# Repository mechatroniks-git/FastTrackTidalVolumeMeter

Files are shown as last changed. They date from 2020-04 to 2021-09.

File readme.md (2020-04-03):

# Fast Track Tidal Volume Meter

Open Source device to measure tidal volume

## Background

Standalone tidal flow meters do not exist. The goal of this device is to allow anyone to have independent monitoring of tidal volume. 

### Making Device

Currently the device is made using the following

* Olimex ESP32-POE-ISO
* SSD1306 .96" OLED
* Sensirion SFM3300 flow sensor
* PCBA (in development)

## Notes

FDA HAS NOT AUTHORIZED USE OF THIS DEVICE, DESIGNS, SOURCE CODE OR DESCRIPTIONS.

## Licence

CERN Open Hardware Licence Version 2 - Permissive See licence file for more info.

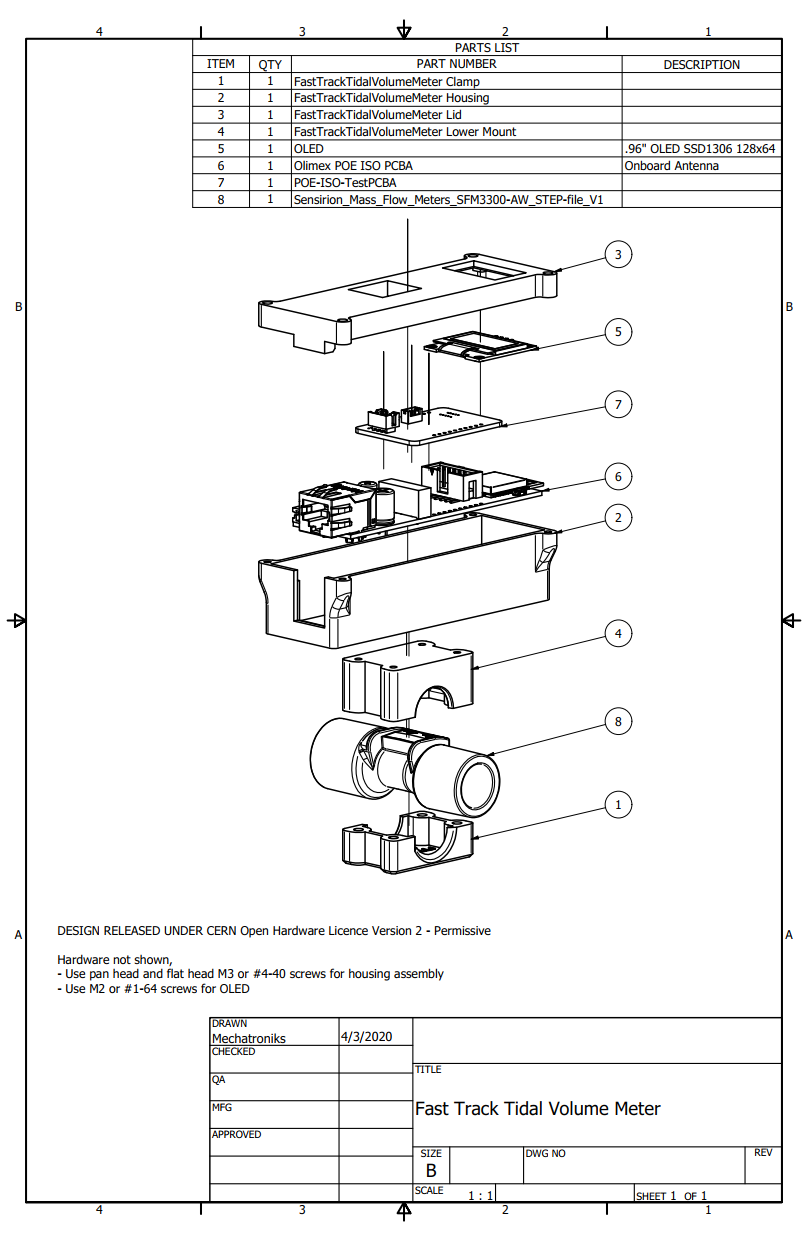
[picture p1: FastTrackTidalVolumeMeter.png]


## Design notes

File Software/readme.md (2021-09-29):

For Spirometer, use the code in this folder

For a simple flow meter useful for testing, use the code in /Flow Meter Build folder. Note, this code doesn't use wifi.

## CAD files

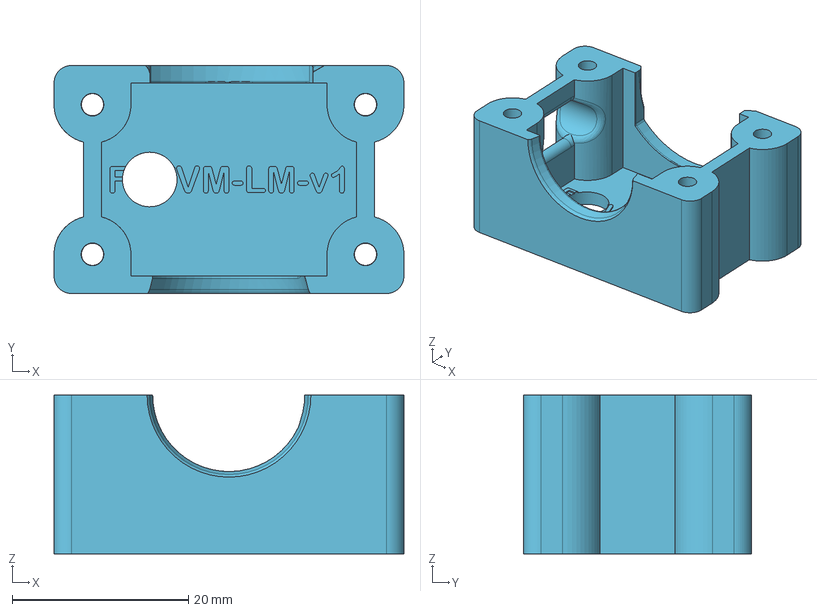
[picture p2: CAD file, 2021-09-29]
Mechanical/makeParts/FastTrackTidalVolumeMeter Lower Mount.stp
39.7 x 25.9 x 18.0 mm

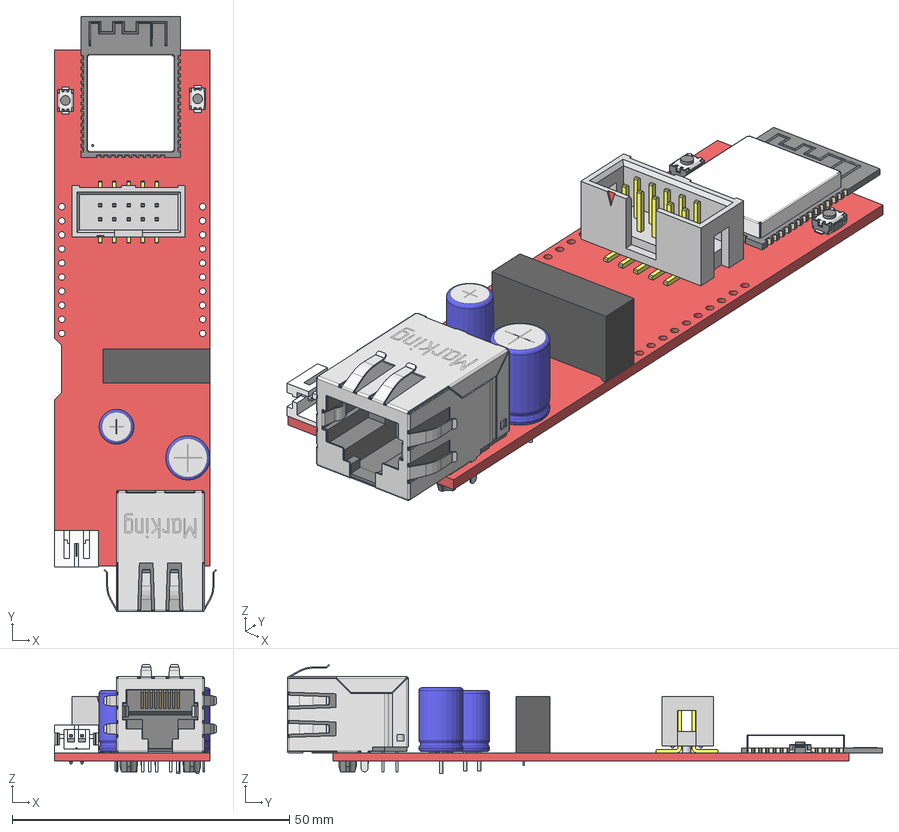
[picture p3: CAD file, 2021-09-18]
PCB/Olimex POE ISO PCBA.stp
29.2 x 107.4 x 19.7 mm
Olimex POE ISO PCB
Olimex POE ISO C29
Olimex POE ISO C27
insulator
shielding
ESP-WROOM-32D
Pushbutton IT1185AU2 x 2
Olimex POE ISO BAT1 JST PH 2 Pin DW02R
User Library-HTST-105-01-F-DV-A__HTST-105-01-DV-A_header
User Library-HTST-105-01-F-DV-A__HTST-First_Position_Indicator
User Library-HTST-105-01-F-DV-A__T-1S6-05-01-DV_
Olimex POE ISO DCDC1 Mornsun F0505S-2WR2

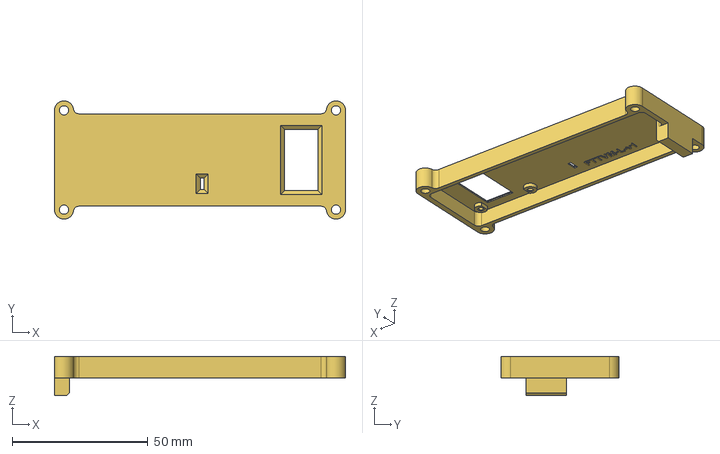
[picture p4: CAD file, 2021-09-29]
Mechanical/makeParts/FastTrackTidalVolumeMeter Lid.stp
107.0 x 43.5 x 14.5 mm

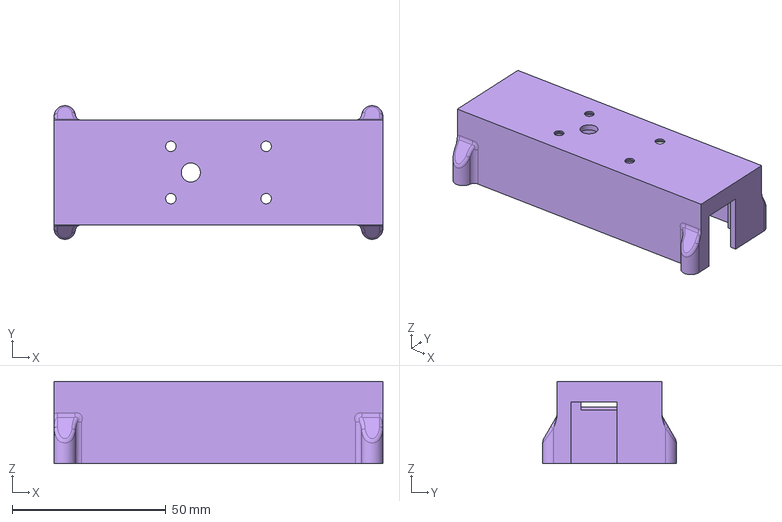
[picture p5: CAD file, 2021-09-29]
Mechanical/makeParts/FastTrackTidalVolumeMeter Housing.stp
107.0 x 43.5 x 26.8 mm

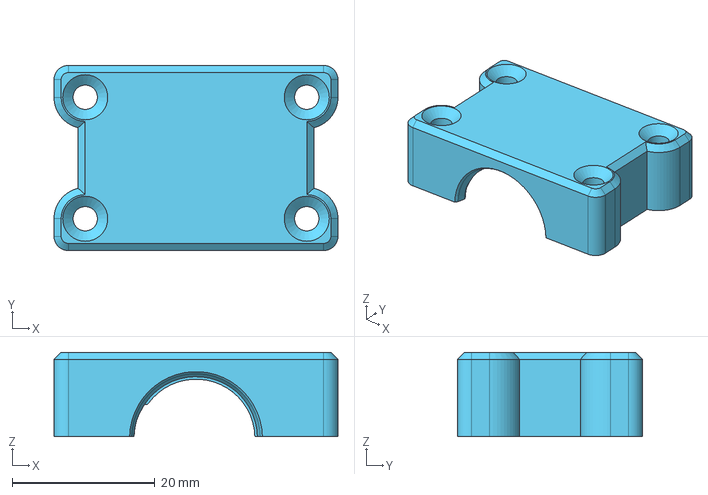
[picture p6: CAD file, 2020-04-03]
Mechanical/makeParts/FastTrackTidalVolumeMeter Clamp.stp
39.7 x 25.9 x 11.8 mm

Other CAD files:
Mechanical/makeParts/FastTrackTidalVolumeMeter Clamp.stl
Mechanical/makeParts/FastTrackTidalVolumeMeter Housing.stl
Mechanical/makeParts/FastTrackTidalVolumeMeter Lid.stl
Mechanical/makeParts/FastTrackTidalVolumeMeter Lower Mount.stl

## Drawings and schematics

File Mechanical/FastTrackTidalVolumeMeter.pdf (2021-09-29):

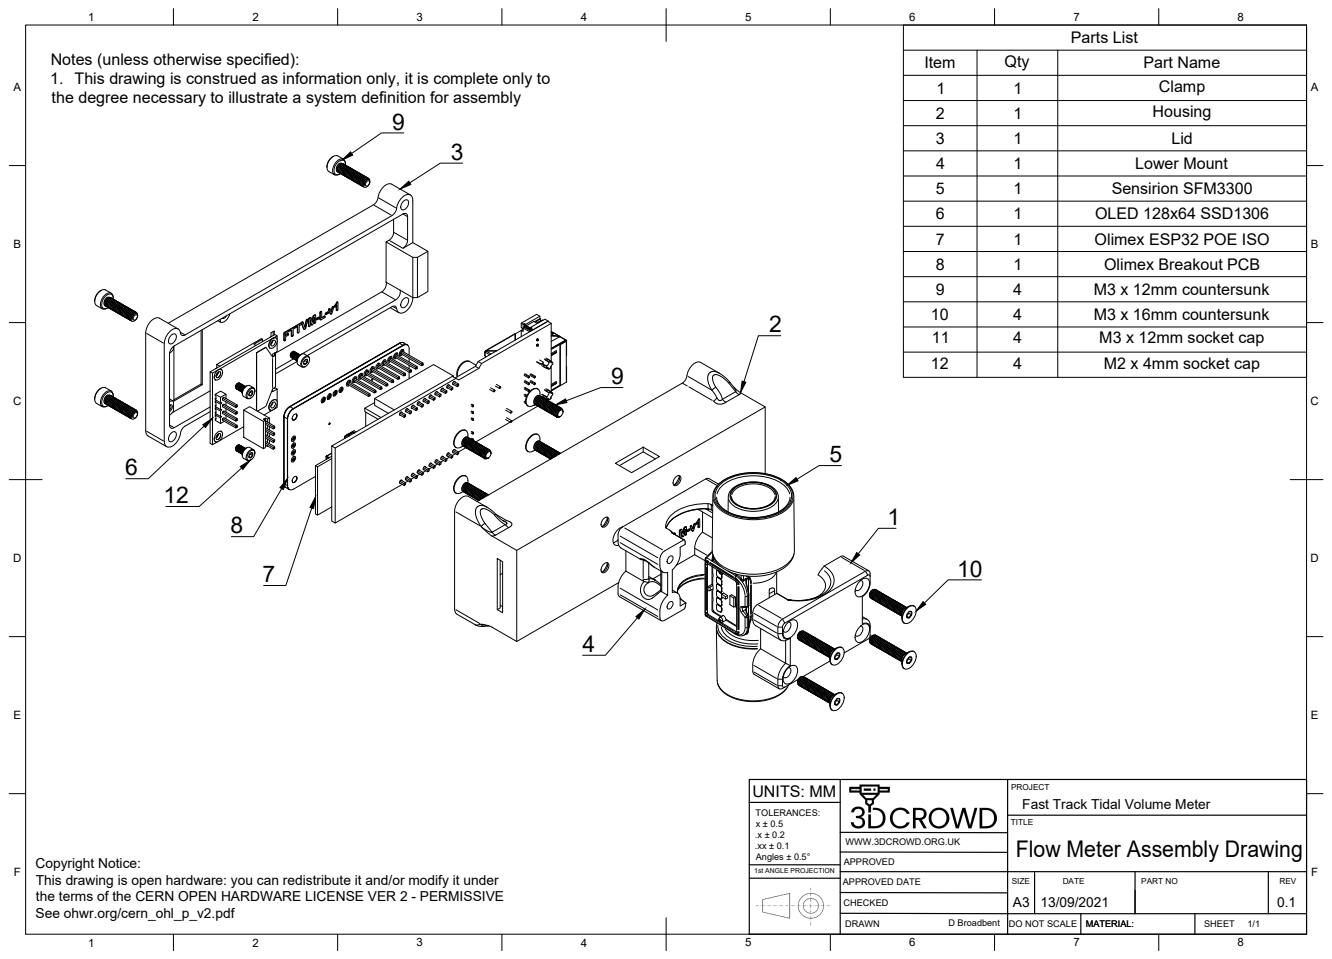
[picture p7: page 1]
UNITS: MM; Angles ± 0.5° 1st ANGLE PROJECTION; SIZE; DATE; PART NO; DO NOT SCALE; MATERIAL:; APPROVED DATE; D Broadbent; Parts List

Notes (unless otherwise specified):
1. This drawing is construed as information only, it is complete only to
the degree necessary to illustrate a system definition for assembly

Item | Qty | Part Name
1 | 1 | Clamp
2 | 1 | Housing
3 | 1 | Lid
4 | 1 | Lower Mount
5 | 1 | Sensirion SFM3300
6 | 1 | OLED 128x64 SSD1306
7 | 1 | Olimex ESP32 POE ISO
8 | 1 | Olimex Breakout PCB
9 | 4 | M3 x 12mm countersunk
10 | 4 | M3 x 16mm countersunk
11 | 4 | M3 x 12mm socket cap
12 | 4 | M2 x 4mm socket cap

PROJECT
Fast Track Tidal Volume Meter

TITLE
Flow Meter Assembly Drawing

WWW.3DCROWD.ORG.UK

Copyright Notice:
This drawing is open hardware: you can redistribute it and/or modify it under
the terms of the CERN OPEN HARDWARE LICENSE VER 2 - PERMISSIVE
See ohwr.org/cern_ohl_p_v2.pdf

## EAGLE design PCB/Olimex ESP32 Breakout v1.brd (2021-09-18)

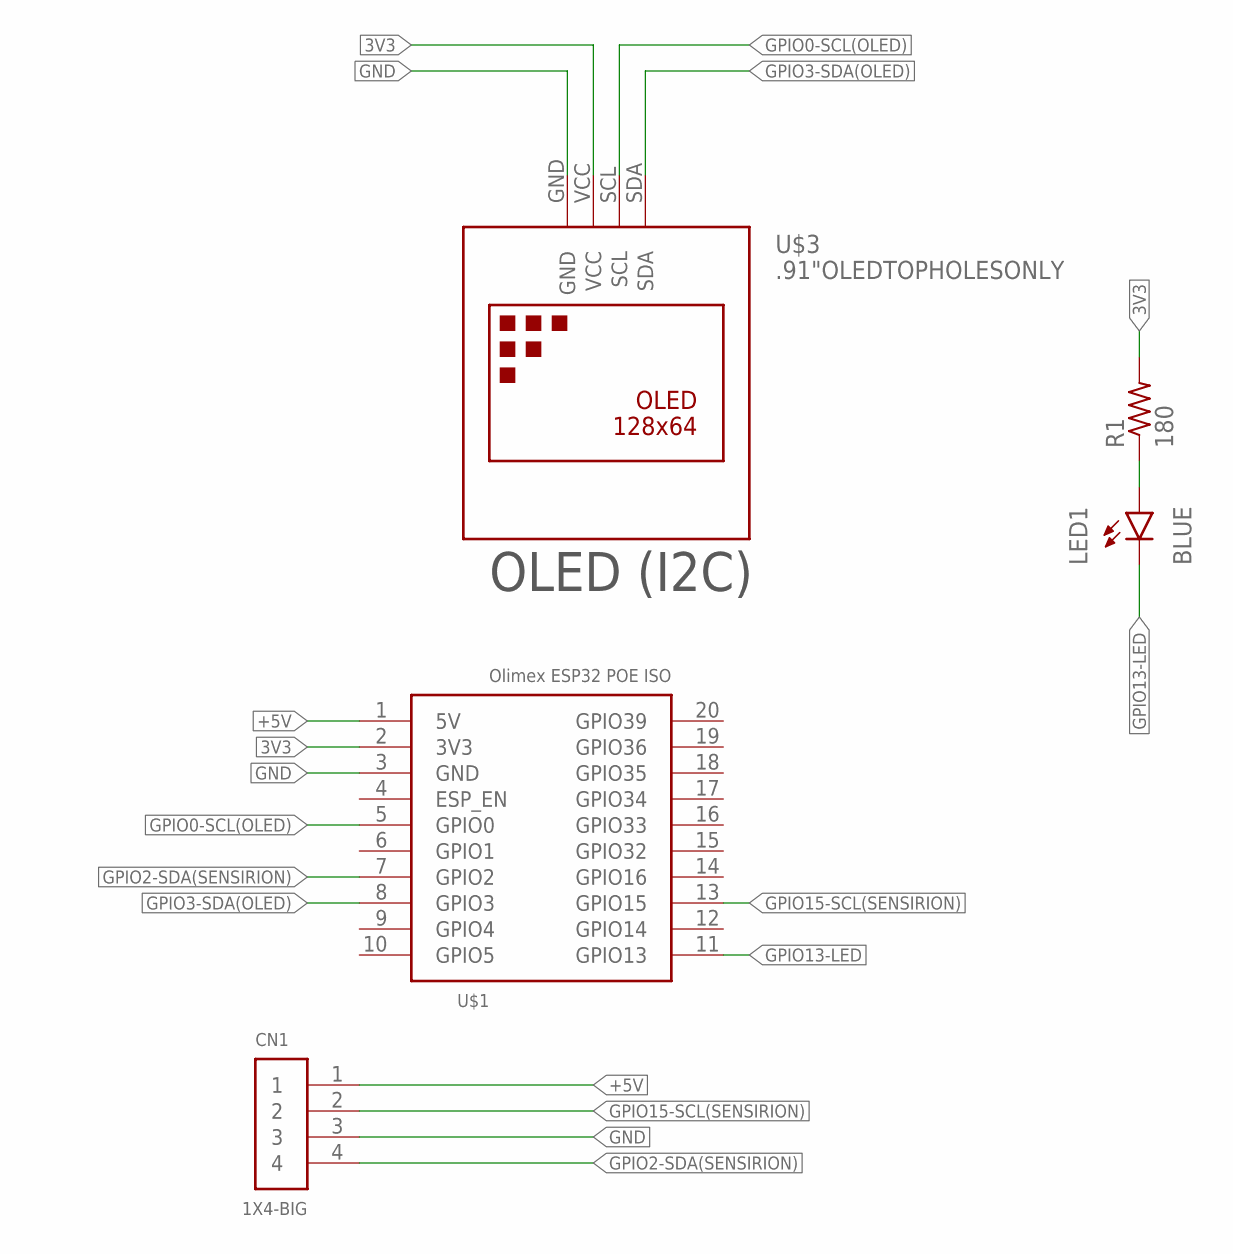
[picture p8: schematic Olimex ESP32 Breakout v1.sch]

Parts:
CN1: 1X4-BIG; 1X04-BIG
LED1: BLUE; LED-1206
R1: 180; R0805
U$1: OLIMEX_POE_ISOPOEISO; OLIMEX_POE_ISO
U$3: .91"OLEDTOPHOLESONLY; .96"OLED-TOPHOLESONLY

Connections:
3V3: R1.2, U$1.2 (3V3), U$3.VCC
+5V: CN1.1, U$1.1 (5V)
BLUEX: LED1.A, R1.1
GND: CN1.3, U$1.3 (GND), U$3.GND
GPIO0-SCL(OLED): U$1.5 (GPIO0), U$3.SCL
GPIO2-SDA(SENSIRION): CN1.4, U$1.7 (GPIO2)
GPIO3-SDA(OLED): U$1.8 (GPIO3), U$3.SDA
GPIO13-LED: LED1.C, U$1.11 (GPIO13)
GPIO15-SCL(SENSIRION): CN1.2, U$1.13 (GPIO15)

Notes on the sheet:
OLED (I2C)

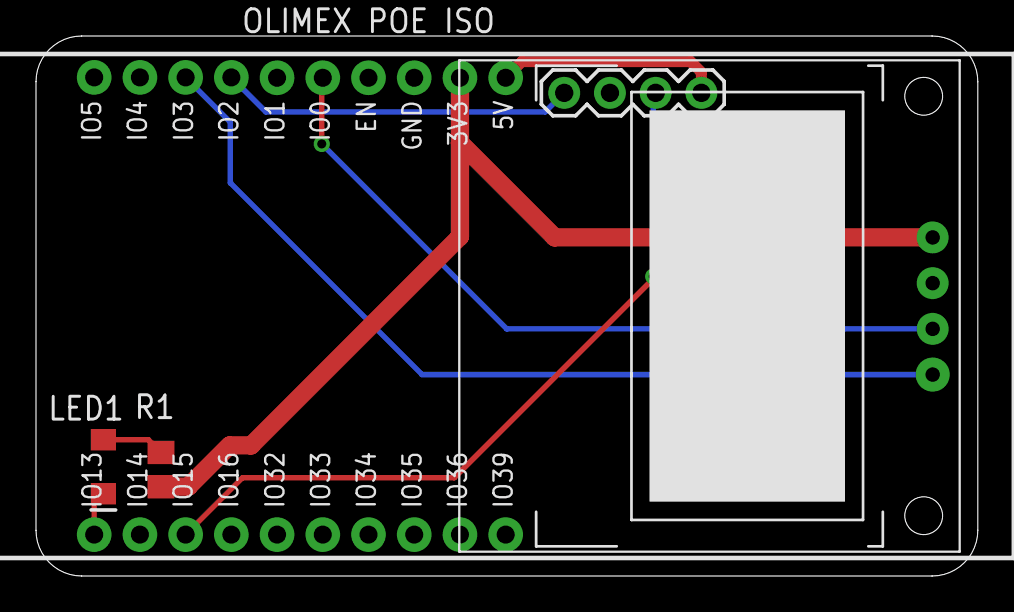
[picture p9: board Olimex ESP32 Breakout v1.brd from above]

Board: 2 copper layers, 52.3 x 30.0 mm, 5 parts (0 on the bottom side), 9 nets.

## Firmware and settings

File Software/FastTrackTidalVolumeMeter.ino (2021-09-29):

/*
Copyright (c) 2020 Mechatroniks
This software is licensed under the CERN CERN Open Hardware Licence Version 2 - Permissive. 
Source: github.com/mechatroniks-git
*/

#include <Wire.h> // Arduino Built-in
#include <Arduino.h> // Arduino AVR core
#include <HardwareSerial.h> // Arduino AVR core
#include <WiFi.h> // Arduino Built-in
#include <Time.h> // PaulStoffregen - Time
#include <SSD1306Wire.h> // https://github.com/ThingPulse/esp8266-oled-ssd1306
#include <ESPAsyncWebServer.h> // https://github.com/me-no-dev/ESPAsyncWebServer also requires https://github.com/me-no-dev/AsyncTCP
#include "esp32config.h" // This project



HardwareSerial hwSerial(1); 

SSD1306Wire display(0x3c, esp32I2CSDA, esp32I2CSCL);  // i2c # 1

extern TwoWire Wire1; // i2c #2

// Replace with your network credentials
const char* ssid     = "#ssid#";
const char* password = "#password#";
const double conversionFactor = 60000;
const int skipCount = 20; //update rate in mS
const int averageCount = 50; //sample averaging time in ms
const double minTidalVolume = 10.0;
double flowTrigger = 2.6;
double lastTidalVolume=0.0;
String sTidalVolume;
String sFlowRate;
String ipAddress;
  
// Set web server port number to 80
AsyncWebServer server(80);

const char index_html[] PROGMEM = R"rawliteral(
<!DOCTYPE HTML><html>
<head>
  <meta http-equiv="refresh" content="2">
  <link rel="stylesheet" href="https://use.fontawesome.com/releases/v5.13.0/css/all.css">
  <style>
    html {
     font-family: Arial;
     display: inline-block;
     margin: 0px auto;
     text-align: center;
    }
    h2 { font-size: 3.0rem; }
    p { font-size: 3.0rem; }
    .units { font-size: 1.2rem; }
    .dht-labels{
      font-size: 1.5rem;
      vertical-align:middle;
      padding-bottom: 15px;
    }
  </style>
</head>
<body>
  <h2>TidalVolume</h2>
  <p>
    <i class="fas fa-lungs" style="color:#059e8a;"></i> 
    <span class="tv-labels">TidalVolume</span> 
    <span id="temperature">%TIDALVOLUME%</span>
    <sup class="units">mL</sup>
  </p>
</body>
<script>
setInterval(function ( ) {
  var xhttp = new XMLHttpRequest();
  xhttp.onreadystatechange = function() {
    if (this.readyState == 4 && this.status == 200) {
      document.getElementById("tidalvolume").innerHTML = this.responseText;
    }
  };
  xhttp.open("GET", "/tidalvolume", true);
  xhttp.send();
}, 10000 ) ;

</script>
</html>)rawliteral";

String readTidalVolume() {
  return String(lastTidalVolume);
}

String readTimeElapsed() {
  return String(lastTidalVolume);
}


String toString(const IPAddress& address){
  return String(address[0]) + "." + address[1] + "." + address[2] + "." + address[3];
}

// Replaces placeholder with TidalVolume values
String processor(const String& var){
  //Serial.println(var);
  if(var == "TIDALVOLUME"){
    return readTidalVolume();
  }
  return String();
}

void setupOled(){
  display.init();
  display.flipScreenVertically();
  display.clear();
  display.setTextAlignment(TEXT_ALIGN_LEFT);
  display.setFont(ArialMT_Plain_16);
  display.drawString(0, 0, "Spirometer");
  display.setFont(ArialMT_Plain_10);
  display.drawString(0, 45, "5/27/2020");
  display.display();
  display.setTextAlignment(TEXT_ALIGN_LEFT);
}

void setupSerial() {
  Serial.begin(115200);
  hwSerial.begin(115200, SERIAL_8N1, esp32Uart2Rx, esp32Uart2Tx);
}

void setupFlowSensor() {
  pinMode(SDA_2,INPUT_PULLUP); // SDA
  pinMode(SCL_2,INPUT_PULLUP); // SCL
  Wire1.begin(SDA_2, SCL_2, 100000); //begin(int sdaPin, int sclPin, uint32_t frequency)

  delay(500);

  Wire1.beginTransmission(byte(0x40)); // transmit to device #064 (0x40)
  Wire1.write(byte(0x10));      //
  Wire1.write(byte(0x00));      //
  Wire1.endTransmission(); 

  delay(5);

  Wire1.requestFrom(0x40, 3); //
  int a = Wire1.read(); // first received byte stored here
  int b = Wire1.read(); // second received byte stored here
  int c = Wire1.read(); // third received byte stored here
  Wire1.endTransmission();
  hwSerial.print(a);
  hwSerial.print(b);
  hwSerial.println(c);

  delay(5);
 
  Wire1.requestFrom(0x40, 3); //
  a = Wire1.read(); // first received byte stored here
  b = Wire1.read(); // second received byte stored here
  c = Wire1.read(); // third received byte stored here
  Wire1.endTransmission();
  hwSerial.print(a);
  hwSerial.print(b);
  hwSerial.println(c);

  delay(5);
}

void setupWifi(){
  hwSerial.print("Connecting to ");
  hwSerial.println(ssid);
  WiFi.begin(ssid, password);
  int noWiFiCounter = 0;
  while ((WiFi.status() != WL_CONNECTED ) && (noWiFiCounter < 12) ) {
    delay(500);
    noWiFiCounter++;
    hwSerial.print(".");
  }
  if (WiFi.status() != WL_CONNECTED ) {
     hwSerial.println("no WiFi found");
     ipAddress = "SSID Not Found";
  }
  else {
    // Print local IP address and start web server
    hwSerial.println("");
    hwSerial.println("WiFi connected.");
    hwSerial.println("IP address: ");
    ipAddress = toString(WiFi.localIP());
    //hwSerial.println(WiFi.localIP());
    hwSerial.println(ipAddress);
    // Route for root / web page
    server.on("/", HTTP_GET, [](AsyncWebServerRequest *request){
      request->send_P(200, "text/html", index_html, processor);
    });
    server.on("/tidalvolume", HTTP_GET, [](AsyncWebServerRequest *request){
      request->send_P(200, "text/plain", readTidalVolume().c_str());
    });
    // Start server
    server.begin();
    hwSerial.println("Server started");
  }
}

void setup() {
  setupSerial();
  Serial.println("Serial Setup");
  hwSerial.println("Serial Setup");
  setupOled();
  Serial.println("OLED Setup");
  hwSerial.println("OLED Setup");
  setupFlowSensor();  
  Serial.println("FlowSensor Setup");
  hwSerial.println("FlowSensor Setup");
  setupWifi();
  Serial.println("WiFi Setup");
  hwSerial.println("WiFi Setup");
}

//CRC
#define POLYNOMIAL 0x131 //P(x)=x^8+x^5+x^4+1 = 100110001

uint8_t crc8(uint8_t data[], uint8_t nbrOfBytes)  {
  uint8_t crc = 0;
  uint8_t byteCtr;
  //calculates 8-Bit checksum with given polynomial
  for (byteCtr = 0; byteCtr < nbrOfBytes; ++byteCtr) { 
    crc ^= (data[byteCtr]);
    for (uint8_t bit = 8; bit > 0; --bit) { 
      if (crc & 0x80) {
        crc = (crc << 1) ^ POLYNOMIAL;
      }
      else {
        crc = (crc << 1);
      }
    }
  }
  return crc;
} 

double getFlow() {
  uint8_t iicData[3];
  uint8_t mycrc;
  uint16_t measuredValue;
  uint16_t offsetFlow = 32768; // Offset for the sensor
  double Flow;
  double scaleFactorFlow = 120.0; // Scale factor for Air and N2 is 120.0
  double calibrationOffset = 0.0;    // device 1
  //double calibrationOffset = 0.07; // device 0
  Wire1.requestFrom(0x40, 3); // read 3 bytes from device with address 0x40
  iicData[0] = Wire1.read(); // first received byte stored here. The variable "uint16_t" can hold 2 bytes, this will be relevant later
  iicData[1] = Wire1.read(); // second received byte stored here
  measuredValue = (iicData[0] * 0x100) + iicData[1];
  iicData[2] = Wire1.read(); // crc value stored here
  if ( (iicData[0] == 0xff) && (iicData[1] == 0xff) && (iicData[2] = 0xff) ) {
    // invalid data
    return(0);
  }
  else {
    mycrc = crc8(iicData, 2);  // calc CRC
    if (mycrc != iicData[2]) { // check if the calculated and the received CRC byte matches
      hwSerial.print("CRC error | ");
      hwSerial.print(iicData[0], HEX);
      hwSerial.print(" | ");
      hwSerial.print(iicData[1], HEX);
      hwSerial.print(" | ");
      hwSerial.print(iicData[2], HEX);
      hwSerial.print(" > ");
      hwSerial.println(mycrc, HEX);    
      Flow = 0.00;
    }
    else {
      //Flow = -(((double)(measuredValue - offsetFlow) / scaleFactorFlow) + calibrationOffset); // flow in liters/min
      Flow = (((double)(measuredValue - offsetFlow) / scaleFactorFlow) + calibrationOffset); // flow in liters/min
    }
    return(Flow);
  }
}

void updateDisplay(double elapsedSeconds) {
  display.clear();
  display.setTextAlignment(TEXT_ALIGN_LEFT);
  display.setFont(ArialMT_Plain_16);
  display.drawString(0, 0, "TVol = " + sTidalVolume +" mL");
  //display.drawString(0, 0, "f= " + sFlowRate);
  display.setFont(ArialMT_Plain_10);
  display.drawString(0, 25, "Last = " + String(elapsedSeconds) +" sec");
  display.setFont(ArialMT_Plain_10);
  display.drawString(0, 45, ipAddress );
  display.display();
}

void updatePlot(double flow, double tidalVolume, uint32_t timeUs) {
  //Serial.print(timeUs); // print the calculated flow to the serial interface
  //Serial.print("\t"); // print the calculated flow to the serial interface
  Serial.print("SLMx10:");
  Serial.print(flow*10); // print the calculated flow to the serial interface
  Serial.print("\t"); // print the calculated flow to the serial interface
  Serial.print("TidalVol:");
  Serial.println(tidalVolume); // print the calculated flow to the serial interface
}

void loop() {
  String currentLine = "";
  int skip = 0; 
  double flow = 0.0;
  double lastFlow =0.0;
  double flowRunningSum = 0;
  double flowAverage = 0;
  String sFlow;
  uint32_t nowUs = micros();
  uint32_t lastUs = 0;
  uint32_t elapsedUs = 0; 
  uint32_t startUs = 0;
  double tidalVolume = 0.0;
  uint32_t lastMilliSec = 0;
  Serial.println("Starting Main");
  while (true) {
    flow = getFlow();
    lastUs = micros();
    if ((flow + lastFlow)/2 > flowTrigger) {
      tidalVolume = 0.0;
      skip = 0;
      startUs = lastUs;
      while ((flow + lastFlow)/2 > flowTrigger) {
        flow = getFlow();
        nowUs = micros();
        elapsedUs = nowUs - lastUs;
        tidalVolume = tidalVolume + ( elapsedUs * (flow + lastFlow)/2);
        flowRunningSum = flowRunningSum + flow - flowAverage;
        flowAverage = flowRunningSum / averageCount;
        skip = skip + 1;
        if (skip > skipCount) {
          updatePlot(flowAverage, tidalVolume/(conversionFactor),nowUs);  
          skip = 0;
          hwSerial.print(flow);
          hwSerial.print('\t');
          hwSerial.print(flowAverage);
          hwSerial.print('\t');
          hwSerial.println(nowUs);
          sFlowRate = String(flowAverage,0.1) + " " + String(flow,0);
          updateDisplay(elapsedUs/1000000);
        }
        lastUs = nowUs;
        lastFlow = flow;
        delay(1);
      }
      tidalVolume = tidalVolume / conversionFactor; // volume in mL (factor out microsec & minutes)
      if (tidalVolume > minTidalVolume) {
        lastTidalVolume = tidalVolume;
        lastMilliSec = millis();
        hwSerial.print("Duration = ");
        hwSerial.println((double)(lastUs - startUs)/1000000);
        hwSerial.print("TidalVolume = ");
        hwSerial.println(lastTidalVolume);
        sTidalVolume = String(tidalVolume,0);
        updateDisplay(double(millis() - lastMilliSec)/1000.0);
      }
    } 
    else {
      flowRunningSum = flowRunningSum + flow - flowAverage;
      flowAverage = flowRunningSum / averageCount;
      if (skip++ > skipCount) {
        sFlowRate = String(flowAverage,0.1) + " " + String(flow,0);
        updatePlot(flowAverage, 0, micros());
        updateDisplay(double(millis() - lastMilliSec)/1000.0);
        skip = 0;
      }
      sFlow = String(flow, 1);
      //hwSerial.println(sFlow);
      delay(1);
    }  
    lastFlow = flow;
  }
}

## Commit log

2020-04-03 Adding mechanical files
    [FastTrackTidalVolumeMeter Clamp-v1.stl, FastTrackTidalVolumeMeter Clamp-v1.stp, FastTrackTidalVolumeMeter Housing-v1.stl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]
2021-09-12 General tidy up of project
    There were 2 sets of .ino and header files in the repo, I have made sure there is only 1 set of the most up to date files and renamed the folder they reside in appropriately. I also added the library sources for external libraries.
    I uploaded the brd and sch files as well as supporting files from the tetra repo. I also added a full set of Gerbers ready for manufacture.
    On the .brd file the labels were the wrong way around for the resistor and the LED so I fixed that.
    I removed a workspace file that was surplus to requirements.
    The reason I have chosen to fork Patricks original repo as opposed to the work in the tetra repo is because it will be easier to maintai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
    [Olimex ESP32 Breakout v1.brd, Olimex ESP32 Breakout v1.sch, Olimex POE ISO PCBA.stp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]
2021-09-17 Removed version numbers from file names
    [FastTrackTidalVolumeMeter Clamp.stl, FastTrackTidalVolumeMeter Clamp.stp, FastTrackTidalVolumeMeter Housing.stl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]
2021-09-17 Make mechanical changes to housing
    - Added hole in lower mount for Sensirion wires to pass through
    - Increased wall thickness around self tapping screws in housing and adjusted lid geometry to match
    - Changed hole in top of lid to match LED position
    [FastTrackTidalVolumeMeter Housing.stl, FastTrackTidalVolumeMeter Housing.stp, FastTrackTidalVolumeMeter Lid.stl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]
2021-09-17 Change stl orientation
    Made it so the orientation of the stls is suitable for printing.
    [FastTrackTidalVolumeMeter Clamp.stl, FastTrackTidalVolumeMeter Housing.stl, FastTrackTidalVolumeMeter Lid.stl]
2021-09-17 Update esp32config.h
    Update pin assignments to be consistent with PCB.
2021-09-17 Increase height of housing to accomodate PCBs and headers
    [FastTrackTidalVolumeMeter Housing.stl, FastTrackTidalVolumeMeter Housing.stp, FastTrackTidalVolumeMeter Lid.stl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]
2021-09-17 Adjust stl orientation
    Adjust stl orientation
    [FastTrackTidalVolumeMeter Housing.stl, FastTrackTidalVolumeMeter Lid.stl]
2021-09-20 Create drill_1_16.xln
    Forgot to add the drill file into the Gerber package.
    [drill_1_16.xln]
2021-09-21 Update FastTrackTidalVolumeMeter.ino
    Update to be consistent with the latest version of the Arduino sketch.
2021-09-29 Flowmeter (#5)
    * flowmeter initial commit
    * Fix pinout to PCB
    * Fix value update on OLED
    * Rename folder
    * Update date
    [SensirionFlowMeter.ino]

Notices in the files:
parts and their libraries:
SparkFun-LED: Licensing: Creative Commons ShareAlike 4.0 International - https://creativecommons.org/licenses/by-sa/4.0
